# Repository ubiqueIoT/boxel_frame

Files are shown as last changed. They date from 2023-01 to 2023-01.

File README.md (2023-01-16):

# Boxel Frame
### Desktop Pixel Art Display

Pixel art has always struck a nostalgic chord. In an effort to perfect my workspace, I thought that a pixel art display case might be in order. This repository details the build process of my pixel frame. I tried to use as many off the shelf components as possible as to keep it easily reproducible.



OnShape was used to build the case for this project. You can find the project source [here](https://cad.onshape.com/documents/5000a3d49c7a9077d1572ff0/w/f60200444dc0dcea69f2e1f3/e/457eb17b8405f6b113c2318f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).
3D Prints were ordered from JLC PCB, using their SLA service with Black Resin. The STL files can be found in the 3D directory of this repository. 



KiCAD was used to make the adapter PCB. You can find the Gerber files in the PCB folder of this directory. The boards were ordered through [JLC PCB](https://jlcpcb.com/CWH).



The Seeed Studio [XIAO nRF52840](https://amzn.to/3kjpGdO) is used as the main processor. The [RP2040 variant](https://amzn.to/3kjpGdO) _should_ also work, but remains untested.



The display is a [240x240 TFT SPI module from Aliexpress](https://www.aliexpress.us/item/3256803574008408.html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) 



An 8-pin right angle M-F header is required to attach the adapter PCB to the TFT display. 
Longer, [easily available, header rows](https://amzn.to/3Xi4Qdl) can be cut to size using snips.



As for assembly hardware, a few different lengths of M2 screws are used. 
All of these can be found in [an M2 hardware kit](https://amzn.to/3ZSZl6T).

- 4x 12mm M2 screw
- 1x 10mm M2 screw
- 2x 8mm M2 screw
- 7x M2 nut

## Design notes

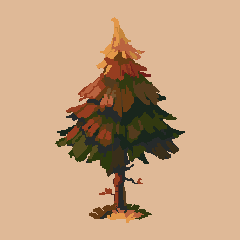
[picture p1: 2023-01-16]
Software/tree.bmp

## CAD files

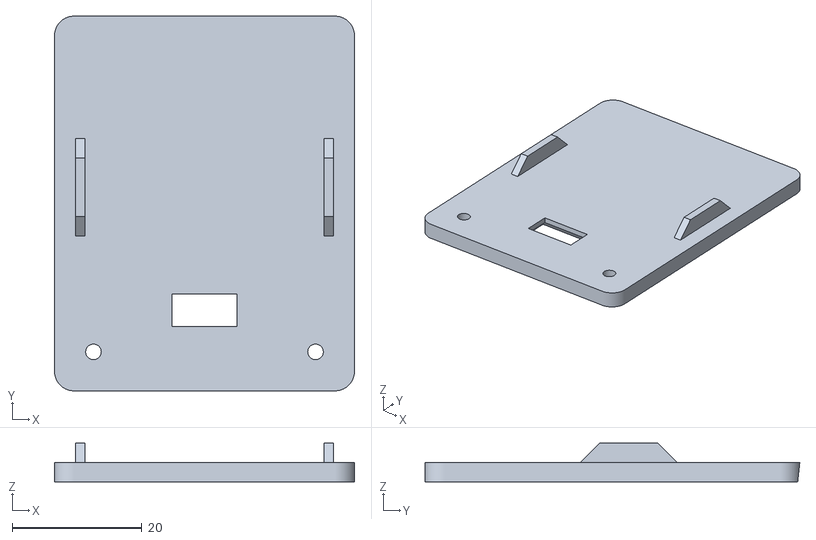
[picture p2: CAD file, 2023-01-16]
3D/Case_lid.stl
46.2 x 57.7 x 6.00

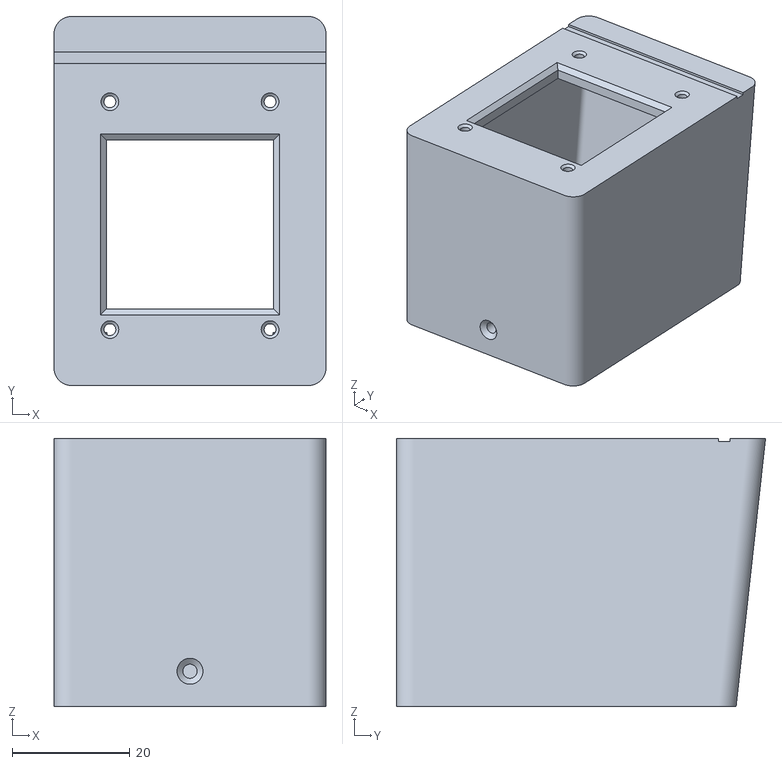
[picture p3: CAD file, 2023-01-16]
3D/Case_body.stl
46.2 x 62.7 x 45.5

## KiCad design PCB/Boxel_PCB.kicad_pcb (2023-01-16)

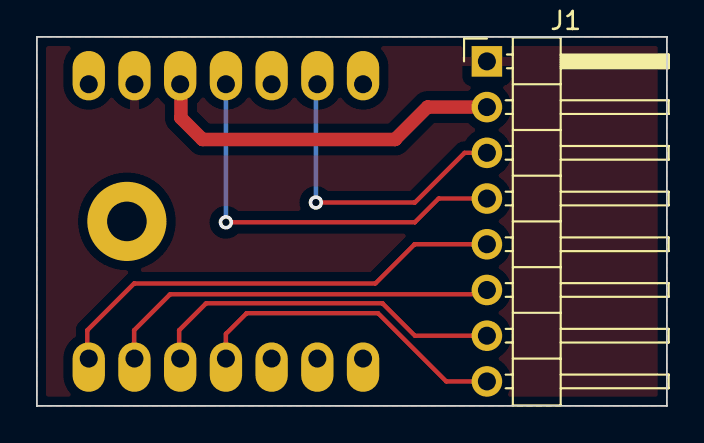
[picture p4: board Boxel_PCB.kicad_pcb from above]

Board: 2 copper layers, 35.0 x 20.5 mm, 3 parts (0 on the bottom side), 8 nets.

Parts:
H1: MountingHole; MountingHole_2.2mm_M2_Pad
J1: Conn_01x08; PinHeader_1x08_P2.54mm_Horizontal
U1: SeeeduinoXIAO; xiao-tht

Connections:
+3V3: J1.2, U1.12 (3V3)
BLK: J1.8, U1.4 (PA11_A3_D3)
CS: J1.7, U1.3 (PA10_A2_D2)
DC: J1.6, U1.2 (PA4_A1_D1)
GND: J1.1, U1.13 (GND)
RES: J1.5, U1.1 (PA02_A0_D0)
SCL: J1.3, U1.9 (PA7_A8_D8_SCK)
SDA: J1.4, U1.11 (PA6_A10_D10_MOSI)

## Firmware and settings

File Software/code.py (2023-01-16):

import board
import terminalio
import displayio
from adafruit_display_text import label
from adafruit_st7789 import ST7789
import adafruit_imageload

spi = board.SPI()
spi = board.SPI()

while not spi.try_lock():
    pass

spi.configure(baudrate=24000000)  # Configure SPI for 24MHz
spi.unlock()

tft_cs = board.D2
tft_dc = board.D1

# Release any resources currently in use for the displays
displayio.release_displays()
display_bus = displayio.FourWire(
    spi, command=tft_dc, chip_select=tft_cs, reset=board.D0
)

display = ST7789(display_bus, width=240, height=240, rowstart=80, rotation=180)

background_sheet, background_palette = adafruit_imageload.load("/tree.bmp",
                                                bitmap=displayio.Bitmap,
                                                palette=displayio.Palette)

# Create the background TileGrid
background = displayio.TileGrid(background_sheet, pixel_shader=background_palette,
                            width = 1,
                            height = 1,
                            tile_width = 240,
                            tile_height = 240)

# Create a Group to hold the background and add it
background_group = displayio.Group(scale=1)
background_group.append(background)

# Create a Group to hold the sprite and background
group = displayio.Group()
group.append(background_group)

display.show(group)

while True:
    pass
